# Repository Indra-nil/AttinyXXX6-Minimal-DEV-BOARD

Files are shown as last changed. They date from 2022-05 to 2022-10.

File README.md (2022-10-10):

# AttinyXXX6-Minimal-DEV-BOARD
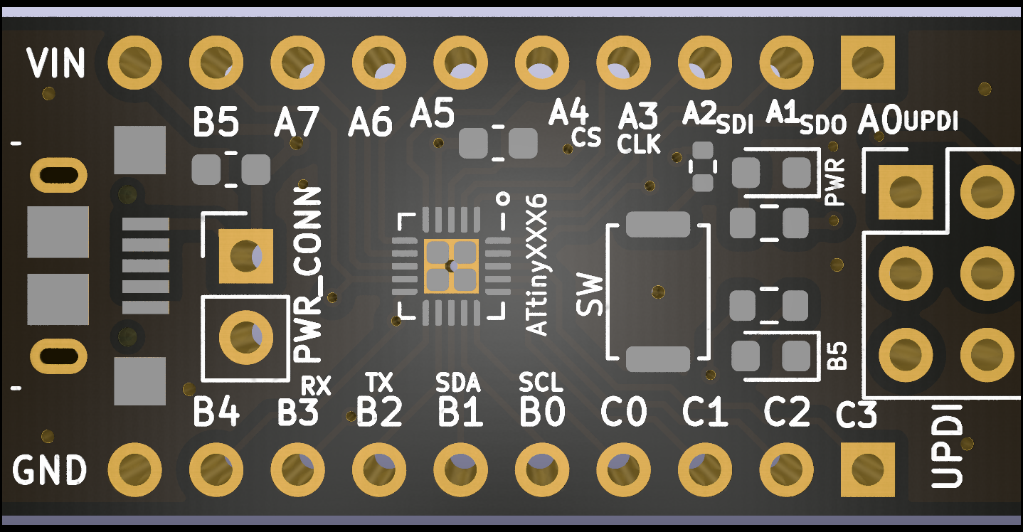
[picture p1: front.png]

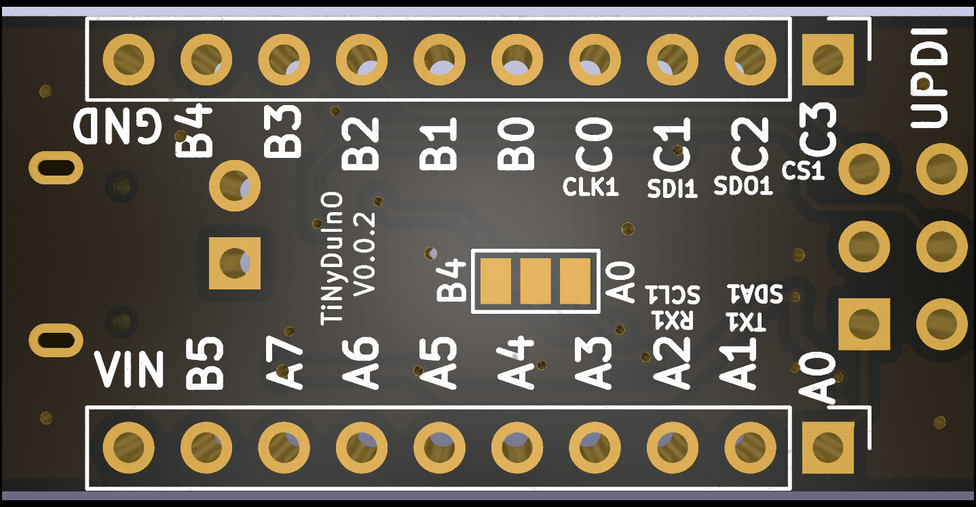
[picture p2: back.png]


This series dev boards are compatible for tinyAVR 0 Series(Attiny406, Attiny806, Attiny1606), tinyAVR 1 Series(Attiny416, Attiny816, Attiny1616, Attiny3216), tinyAVR 2 Series(Attiny426, Attiny826, Attiny1626, Attiny3226) microcontrollers(VQFN-20).

This is a bare minium pcb. For programing, need any kind of UPDI programmer(jtag2Updi, pyupdi, edbg or atmel ICE) and programs can be written on either Arduino or AVR-GCC.

Some useful links
--------------------

[jtag2updi](https://github.com/ElTangas/jtag2updi.git) 

[pyupdi](https://github.com/mraardvark/pyupdi.git)

[Various UPDI hardwares](https://github.com/wagiminator/AVR-Programmer.git)

[megaTinyCore(arduino core)](https://github.com/SpenceKonde/megaTinyCore.git)

[TinyCore(arduino core)](https://github.com/xukangmin/TinyCore.git)

[Microchip Studio for AVR](https://www.microchip.com/en-us/tools-resources/develop/microchip-studio)

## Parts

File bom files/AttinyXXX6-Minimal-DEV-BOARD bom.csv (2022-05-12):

Ref | Qnty | Value | Cmp name | Footprint | MPN
C1, | 1 | 10u | C | Capacitor_SMD:C_0603_1608Metric | CC0603KRX5R6BB106
C2, | 1 | 100n | C | Capacitor_SMD:C_0603_1608Metric | CC0603KRX7R9BB104
D1, | 1 | PWR | LED | LED_SMD:LED_0603_1608Metric | 19-217/R6C-AL1M2VY/3T
D2, | 1 | B5 | LED | LED_SMD:LED_0603_1608Metric | 19-217/G7C-AN1P2/3T
J1, | 1 | USB_B_Micro | USB_B_Micro | MUP-U513:MUP-U513 | MUP-U513
J2, | 1 | PWR_CONN | Conn_01x02_Male | Connector_PinHeader_2.54mm:PinHeader_1x02_P2.54mm_Vertical
J3, | 1 | UPDI | Conn_02x03_Odd_Even | Connector_PinHeader_2.54mm:PinHeader_2x03_P2.54mm_Vertical
J4, J5, | 2 | Conn | Conn_01x10_Male | Connector_PinHeader_2.54mm:PinHeader_1x10_P2.54mm_Vertical
R1, R2, | 2 | 1k | R | Resistor_SMD:R_0603_1608Metric | RC0603FR-071KL
R3, | 1 | 1k | R | Resistor_SMD:R_0402_1005Metric | RC0402JR-071KL
SW1, | 1 | SW | SW_Push_45deg | Button_Switch_SMD:SW_Push_SPST_NO_Alps_SKRK | SKRKAEE020
U1, | 1 | ATtinyXXX6 | ATtiny1616-M | Package_DFN_QFN:VQFN-20-1EP_3x3mm_P0.4mm_EP1.7x1.7mm | ATTINY1616-MN

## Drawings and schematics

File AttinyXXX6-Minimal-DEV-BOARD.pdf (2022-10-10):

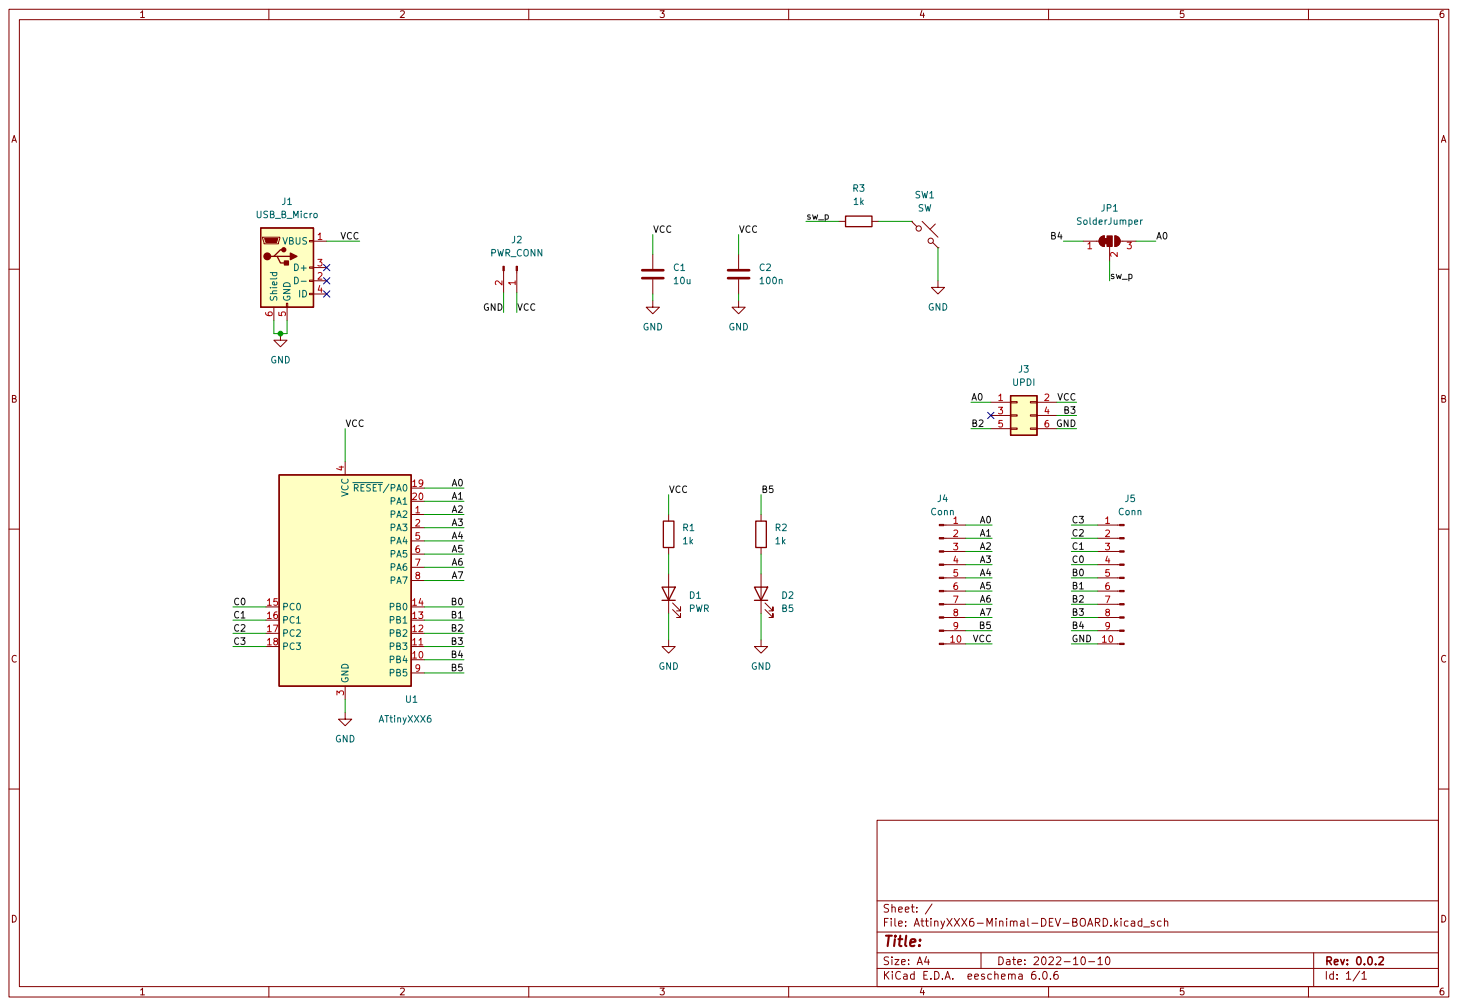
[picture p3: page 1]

File: AttinyXXX6-Minimal-DEV-BOARD.kicad_sch Sheet: /
Id: 1/1 Title:

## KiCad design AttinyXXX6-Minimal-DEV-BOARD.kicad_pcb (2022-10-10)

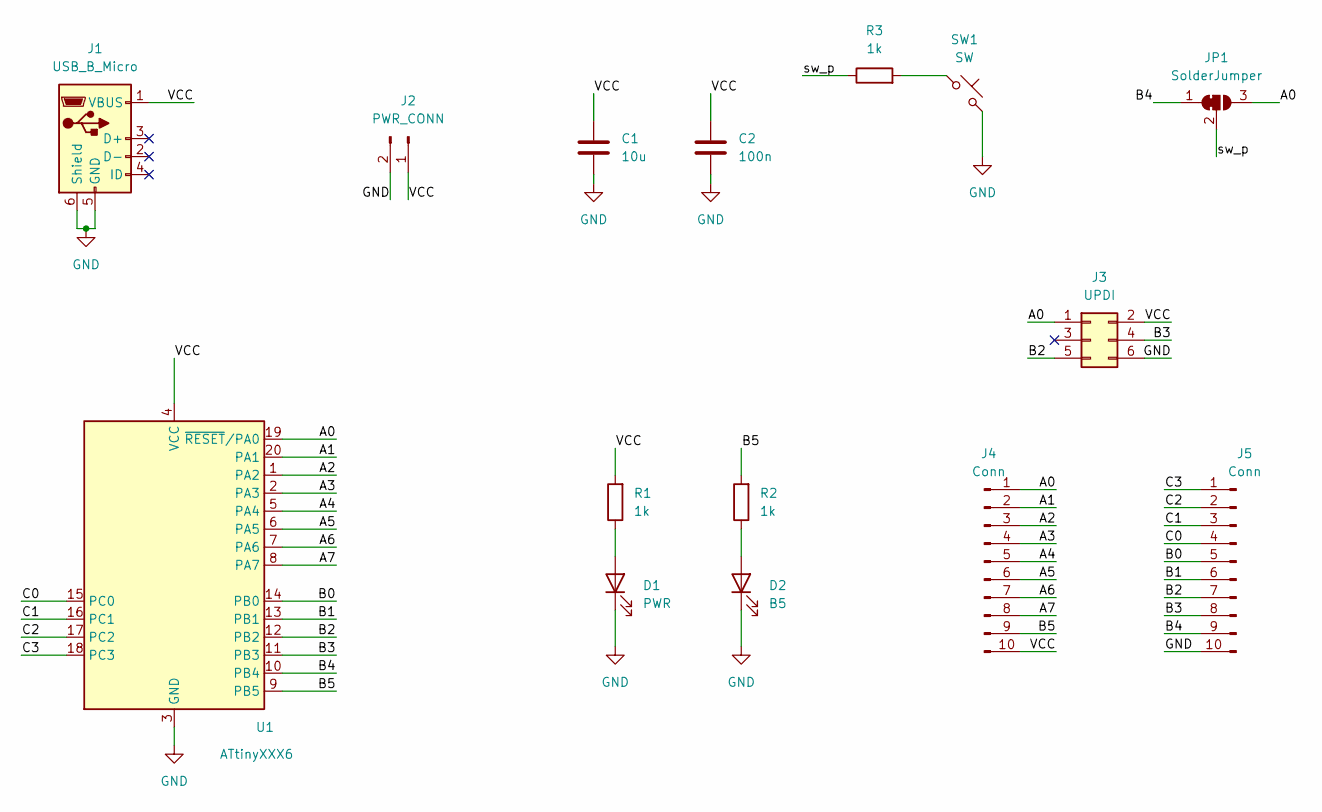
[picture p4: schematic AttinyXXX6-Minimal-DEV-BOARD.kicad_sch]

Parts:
C1: 10u; C_0603_1608Metric
C2: 100n; C_0603_1608Metric
D1: PWR; LED_0603_1608Metric
D2: B5; LED_0603_1608Metric
J1: USB_B_Micro; MUP-U513
J2: PWR_CONN; PinHeader_1x02_P2.54mm_Vertical
J3: UPDI; PinHeader_2x03_P2.54mm_Vertical
J4, J5: Conn; PinHeader_1x10_P2.54mm_Vertical
JP1: SolderJumper; SolderJumper-3_P1.3mm_Bridged12_Pad1.0x1.5mm_NumberLabels
R1, R2: 1k; R_0603_1608Metric
R3: 1k; R_0402_1005Metric
SW1: SW; SW_Push_SPST_NO_Alps_SKRK
U1: ATtinyXXX6; VQFN-20-1EP_3x3mm_P0.4mm_EP1.7x1.7mm

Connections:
/A0: J3.1, J4.1, JP1.3 (B), U1.19 (~RESET/PA0)
/A1: J4.2, U1.20 (PA1)
/A2: J4.3, U1.1 (PA2)
/A3: J4.4, U1.2 (PA3)
/A4: J4.5, U1.5 (PA4)
/A5: J4.6, U1.6 (PA5)
/A6: J4.7, U1.7 (PA6)
/A7: J4.8, U1.8 (PA7)
/B0: J5.5, U1.14 (PB0)
/B1: J5.6, U1.13 (PB1)
/B2: J3.5, J5.7, U1.12 (PB2)
/B3: J3.4, J5.8, U1.11 (PB3)
/B4: J5.9, JP1.1 (A), U1.10 (PB4)
/B5: J4.9, R2.2, U1.9 (PB5)
/C0: J5.4, U1.15 (PC0)
/C1: J5.3, U1.16 (PC1)
/C2: J5.2, U1.17 (PC2)
/C3: J5.1, U1.18 (PC3)
/VCC: C1.1, C2.1, J1.1 (VBUS), J2.1, J3.2, J4.10, R1.2, U1.4 (VCC)
/sw_p: JP1.2 (C), R3.1
GND: C1.2, C2.2, D1.1 (K), D2.1 (K), J1.5 (GND), J1.6 (Shield), J2.2, J3.6, J5.10, SW1.2, U1.3 (GND), U1.21 (GND)
unnamed: D1.2 (A), R1.1
unnamed: D2.2 (A), R2.1
unnamed: R3.2, SW1.1

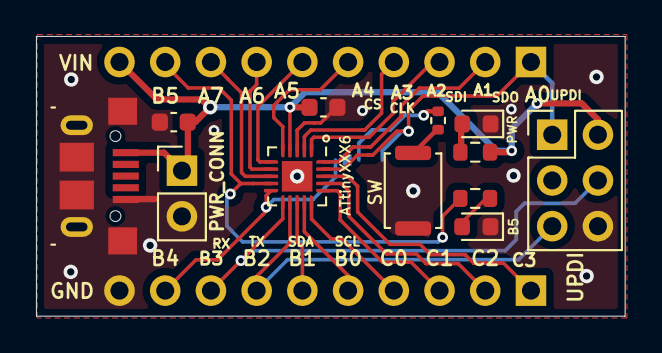
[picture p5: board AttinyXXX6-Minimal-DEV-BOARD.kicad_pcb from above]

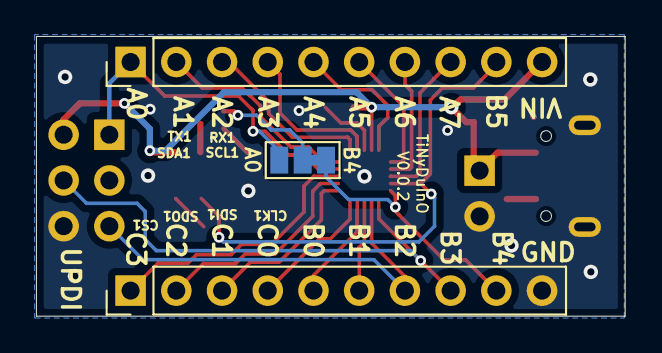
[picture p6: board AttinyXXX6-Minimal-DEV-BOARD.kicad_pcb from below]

Board: 2 copper layers, 32.7 x 15.5 mm, 15 parts (3 on the bottom side), 24 nets.

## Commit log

2022-05-12 initial release
    [AttinyXXX6-Minimal-DEV-BOARD bom.csv, AttinyXXX6-Minimal-DEV-BOARD.kicad_pcb, AttinyXXX6-Minimal-DEV-BOARD.kicad_sch]
2022-10-10 pinout and updi
    PIN B0 location change and UPDI connector pin change to universal one.
    [AttinyXXX6-Minimal-DEV-BOARD.kicad_pcb, AttinyXXX6-Minimal-DEV-BOARD.kicad_sch]
2022-10-10 B0 location and UPDI connector
    PIN B0 location change and UPDI connector changing to universal one
    [AttinyXXX6-Minimal-DEV-BOARD.kicad_pcb, AttinyXXX6-Minimal-DEV-BOARD.kicad_sch]
